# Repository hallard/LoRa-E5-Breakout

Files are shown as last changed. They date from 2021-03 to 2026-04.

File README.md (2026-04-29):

# LoRa-E5 breakout board

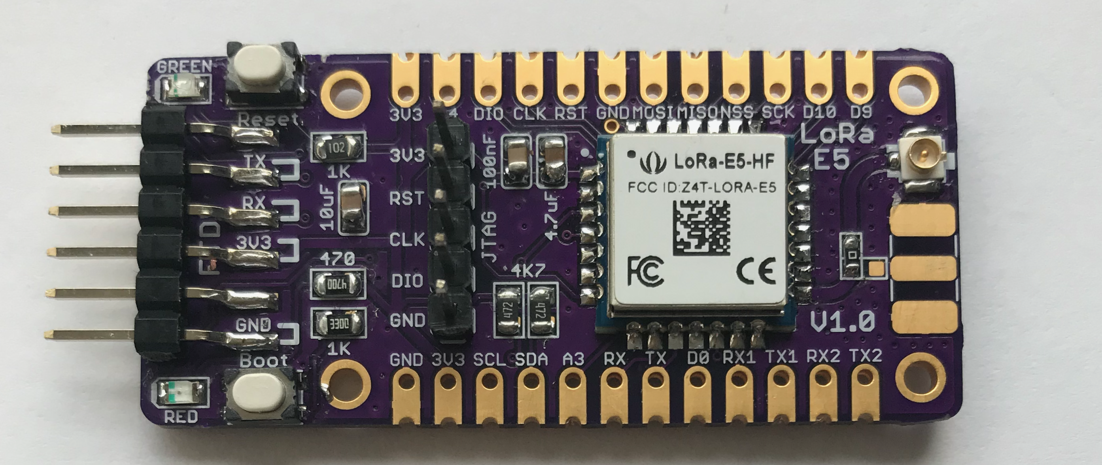
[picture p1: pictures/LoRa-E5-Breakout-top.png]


Mainly based on [LoRa-E5 mini](https://www.seeedstudio.com/LoRa-E5-mini-STM32WLE5JC-p-4869.html) board from Seedstudio, but since it was out of stock and I needed some specific wiring, I designed my own based on the Open Source design they made (thank for sharing)

I'm using mainly to flash custom firmware in it, and not using AT default firmware.

**These boards have been received, assembled, and works as expected**

- LoRa-E5 Module
- No USB/Serial, SMD FTDI 6 pins connector (**use 3.3V FTDI One, not 5V**)
- Exposed JTAG pins needed to flash module (PA13-SWDIO / PA14-SWCLK / RESET)
- Green Led on PB10
- Red Led on PB5
- Optional 2 Tactile Switch (boot and reset)
- 2 Antenna connector (u-Fl and SMA), select with 0 Ohm resistor
- I2C 4 pins location for "classic" sensors

## Detailed Description

No specific documentation for now, it's just a kind of wiring helper as schematic.

I also assume that you are familiar with all LoRaWAN stuff, all setup/infrastructure/network server/provisionning and other are out of scope of this repository.

## Schematics

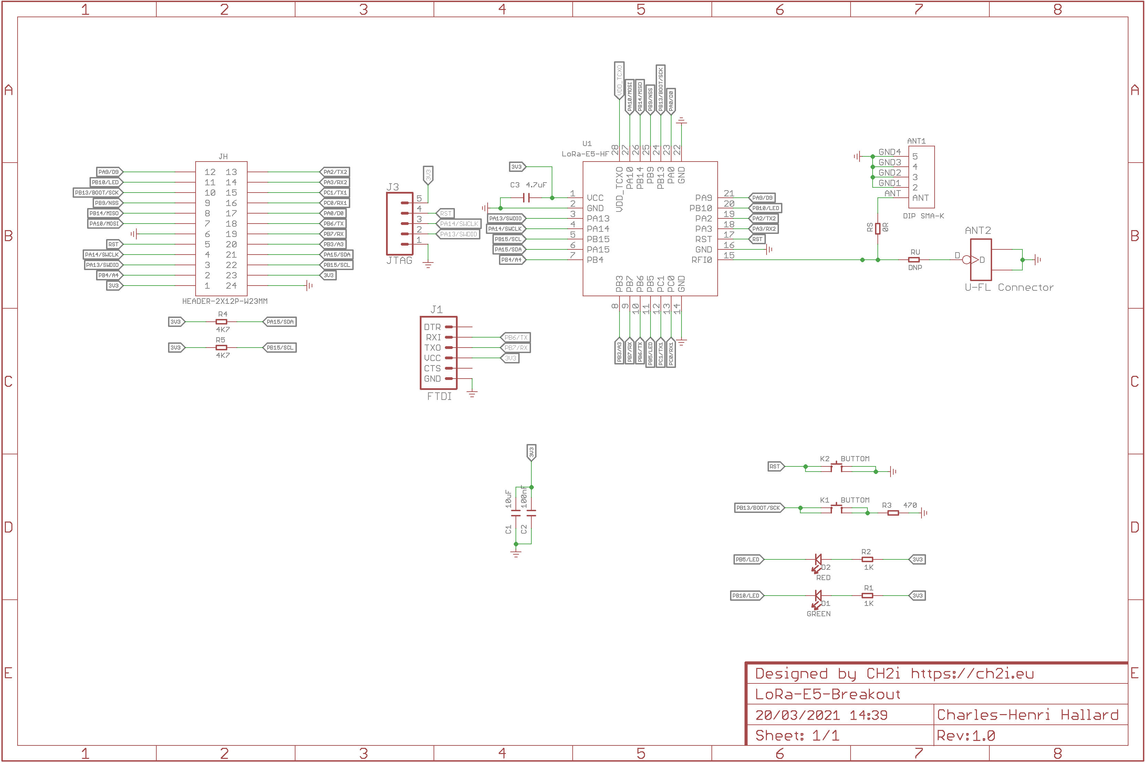
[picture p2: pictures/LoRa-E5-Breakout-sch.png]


## Boards 

~~You can order PCBs of this board at [PCBs.io][3]~~

- ~~[V1.0](https://PCBs.io/share/zM5GG)~~

 ~~PCBs.io give me some reward when you order my designed boards from their site. This is pretty good, because I can use these rewards to create and design new boards and order boards for a discounted price, so if you don't care about PCB manufacturer please use PCBs.io.~~

Looks like PCBs.io is gone, I do not have any rewards from PCBs.io since August 2020 and my free order placed after are still not received, so my guess they are not on business anymore.

So you can order the board on [oshpark](https://oshpark.com). 

- [V1.0](https://oshpark.com/shared_projects/pMgmywYX) 

It's a pitty after several discuss with OSHPark that I can't have any rewards for each people ordering my boards, this would allow me to order free PCB for shared projects and create new ones. For information my shared boards generated a total of **$285 162.00** orders at PCBs.io in 4 years, not bad at all :-)

Hoping one day OSHparks will thanks me giving them this market. 

### Assembled boards

**Top & bottom side V1.0**


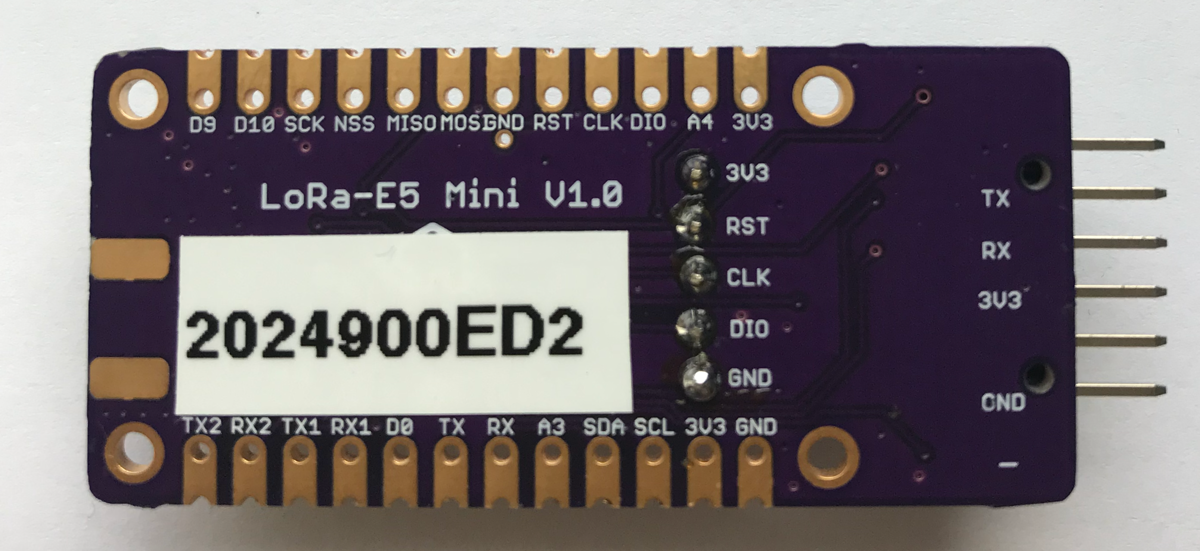
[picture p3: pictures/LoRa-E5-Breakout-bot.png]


### Bill Of Material

Nothing fancy, all components are 0805 and/or PTH and can be ordered almost anywhere (digikey, mouser, radiospare, ...). 
use only what you need dependings on what you want to do. 

Check Seeed format [BOM](https://github.com/hallard/LoRa-E5-Breakout/blob/main/LoRa-E5-Breakout-BOM.xlsx) File, check on [Seeed OPL](https://www.seeedstudio.com/opl.html) for manufacturer SKU match.

## Firmware

Before flashing any custom firmware, I strongly advise to test the board with default AT-Firmware to get the keys (even if you can use your own of course). 

Do do this, use 3.3V (and NOT 5V) FTDI USB/Serial adapter, I love this one from [sparkun](https://www.sparkfun.com/products/14050)


- Connect FTDI on the 6 pins dedicated header of the breakout
- use them a terminal application and open the port on your computer corresponding to the FTDI device
- set terminal settings to 9600 bauds 8 bits no parity 1 stop bit (8N1)
- check with at command `AT` device should anwser ``+AT: OK``

then get keys of the device

```
AT 
+AT: OK
AT+ID 
+ID: DevAddr, 24:90:05:44
+ID: DevEui, 2C:F7:F1:20:24:90:05:44
+ID: AppEui, 80:00:00:00:00:00:00:06
```

### Provision device on Network Server

For testing I'm always using The Things Network (TTN).
So next step is to provision this new device to TTN with the above keys (no need DevAddr) and get APPKEY from TTN (random generate) then get the key issued from TTN (we'll use it later below)

### Compile and flash Firmware

You can flash the board with excellent [mbed-os](https://os.mbed.com/mbed-os/) framework. 
Easy way is to use [mbed studio IDE](https://os.mbed.com/studio/). 
We added this board into [stm32customtargets](https://github.com/ARMmbed/stm32customtargets), don't hesitate to read the [readme](https://github.com/ARMmbed/stm32customtargets/blob/master/README.md). 
Finally the main firmware [mbed-os-example-lorawan](https://github.com/ARMmbed/mbed-os-example-lorawan) program.

Once IDE installed: 

- use `file` / `import program` and them import the example with URL `https://github.com/ARMmbed/mbed-os-example-lorawan`
- right click in the project name and select `Add Library` and enter `https://github.com/ARMmbed/stm32customtargets`
- open the file `custom_targets.json` from folder `stm32customtargets` and copy whole contents
- paste copied contents in the main root folder file `custom_targets.json` (yes replace the whole file) 
- open the file `mbed_app.json` and change parameters on the section `target_overrides`
    - LoRaWAN parameters such as frequency plan, OTAA, Duty Cycle, ...
    - replace keys with the ones you got from above step `lora.device-eui`, `lora.application-eui` and `lora.application-key`
- add the following section near the end of the file `mbed_app.json`.

```json
        "LORA_E5_BREAKOUT": {
            "stm32wl-lora-driver.rf_switch_config": "RBI_CONF_RFO_HP",
            "stm32wl-lora-driver.debug_tx": "PB_5",
            "stm32wl-lora-driver.debug_rx": "PB_10",
            "stm32wl-lora-driver.debug_invert": 1,
            "stm32wl-lora-driver.rf_switch_config": 2,
        }
```

When using any LoRa-E5 board you need to set the line `rf_switch_config` as above to `RBI_CONF_RFO_HP`, because hardware has not wired the mode `RBI_CONF_RFO_LP` and the stack for EU868 will try to use the `RBI_CONF_RFO_LP` (Low Power because 14dB max) path, and thus will result in unreliable signal (see #3). See this [post](https://forum.seeedstudio.com/t/lora-e5-fw-bug-tx-eu868-85ma-too-high-consumption/260126) and this [one](https://forum.rakwireless.com/t/rak3172-too-much-consumption-in-transmit-eu868/4781) for details.

Then on IDE select target "LORA_E5_BREAKOUT", build and flash with your favorite programmer (I'm using STLink) with GND/SWDIO/SWDCLK/RESET connected. 

Pay attention, that 1st time you need to erase SeeeStudio original firmware, make sure the Read Out Protection of the device is AA. If it is shown as BB, select AA and click Apply. See the end of this [section](https://wiki.seeedstudio.com/LoRa_E5_Dev_Board/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) on how to do that with STM32CubeProgrammer.

### Build and Flash

From IDE you can build the example. If you plug your STLink while project opened, mbed ide will ask you if you want to set it up for this project/target, once approved you can compile, flash and even debug from mbed ide (need some tools installed, [read](https://os.mbed.com/docs/mbed-studio/current/monitor-debug/debugging-with-mbed-studio.html), very nice.

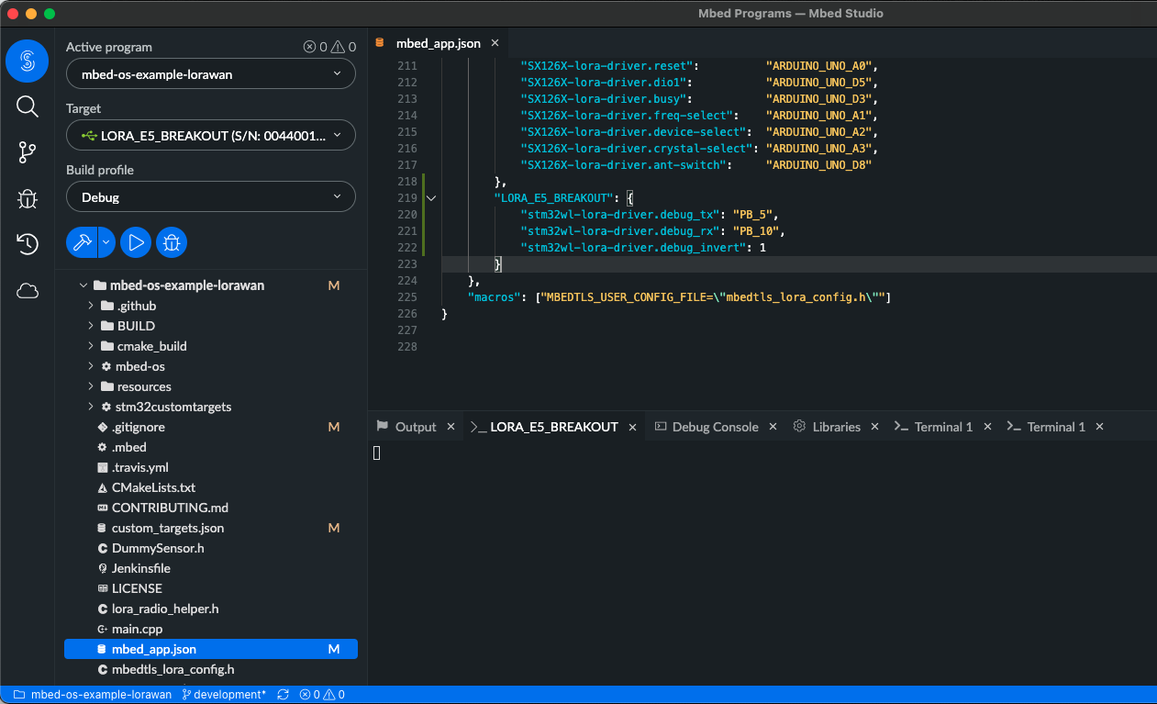
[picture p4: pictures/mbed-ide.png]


You can also see logs with the FTDI adapter and any Serial terminal set to 115200 bauds 8 bits no parity 1 stop bit (8N1)

```
Mbed LoRaWANStack initialized 
 CONFIRMED message retries : 3 
 Adaptive data  rate (ADR) - Enabled 
 Connection - In Progress ...
 Connection - Successful 
 Dummy Sensor Value = 3 
 23 bytes scheduled for transmission 
 Message Sent to Network Server 
 Dummy Sensor Value = 5 
 23 bytes scheduled for transmission 
 Message Sent to Network Server 
 Dummy Sensor Value = 7 
 23 bytes scheduled for transmission 
```

Green LED will be on when on receive mode and Red when sending data.

## License



This work is licensed under a [Creative Commons Attribution-NonCommercial-ShareAlike 4.0 International License](https://creativecommons.org/licenses/by-nc-sa/4.0/).
If you want to do commercial stuff with this project, please contact [CH2i company](https://ch2i.eu/en#support) so we can organize an simple agreement.

Original Seeed Studio reference design at https://wiki.seeedstudio.com/LoRa_E5_mini/

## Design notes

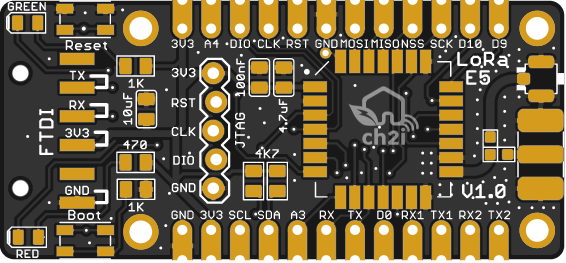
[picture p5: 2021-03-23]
pictures/LoRa-E5-Breakout.png

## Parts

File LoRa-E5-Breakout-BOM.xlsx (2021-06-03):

Designator | Seeed SKU | Qty | Description
U1 | 317990687 | 1 | LoRa-E5 STM32WLE5JC Module
C1 | 302010178 | 1 | SMD CAP Ceramic 10uF-25V-10%-X5R;0805
C2 | 302010165 | 1 | SMD CAP Ceramic 100nF-50V-10%-X7R;0805
C3 | 302010146 | 1 | SMD CAP Ceramic 4.7uF-25V-10%-X5R;0805
RS | 301012029 | 1 | SMD RES 0R-1%-1/10W;0603
R4,R5 | 301010306 | 2 | SMD RES 4.7K 0805
R1, R2 | 301010311 | 2 | SMD RES 1K 0805
R3 | 301010367 | 1 | SMD RES 470 0805
D1 | 304090043 | 1 | SMD LED Clear-Green
D2 | 304090042 | 1 | LED-SMD Red Diffused
K1,K2 | 311020518 | 2 | SMD Top Button 1.57N;4P-L4.6*W3.2*H2.5mm
ANT | 320111077 | 1 | SMD U-FL Female CONN-Gold;3P-L2.6*W2.6*H1.25mm

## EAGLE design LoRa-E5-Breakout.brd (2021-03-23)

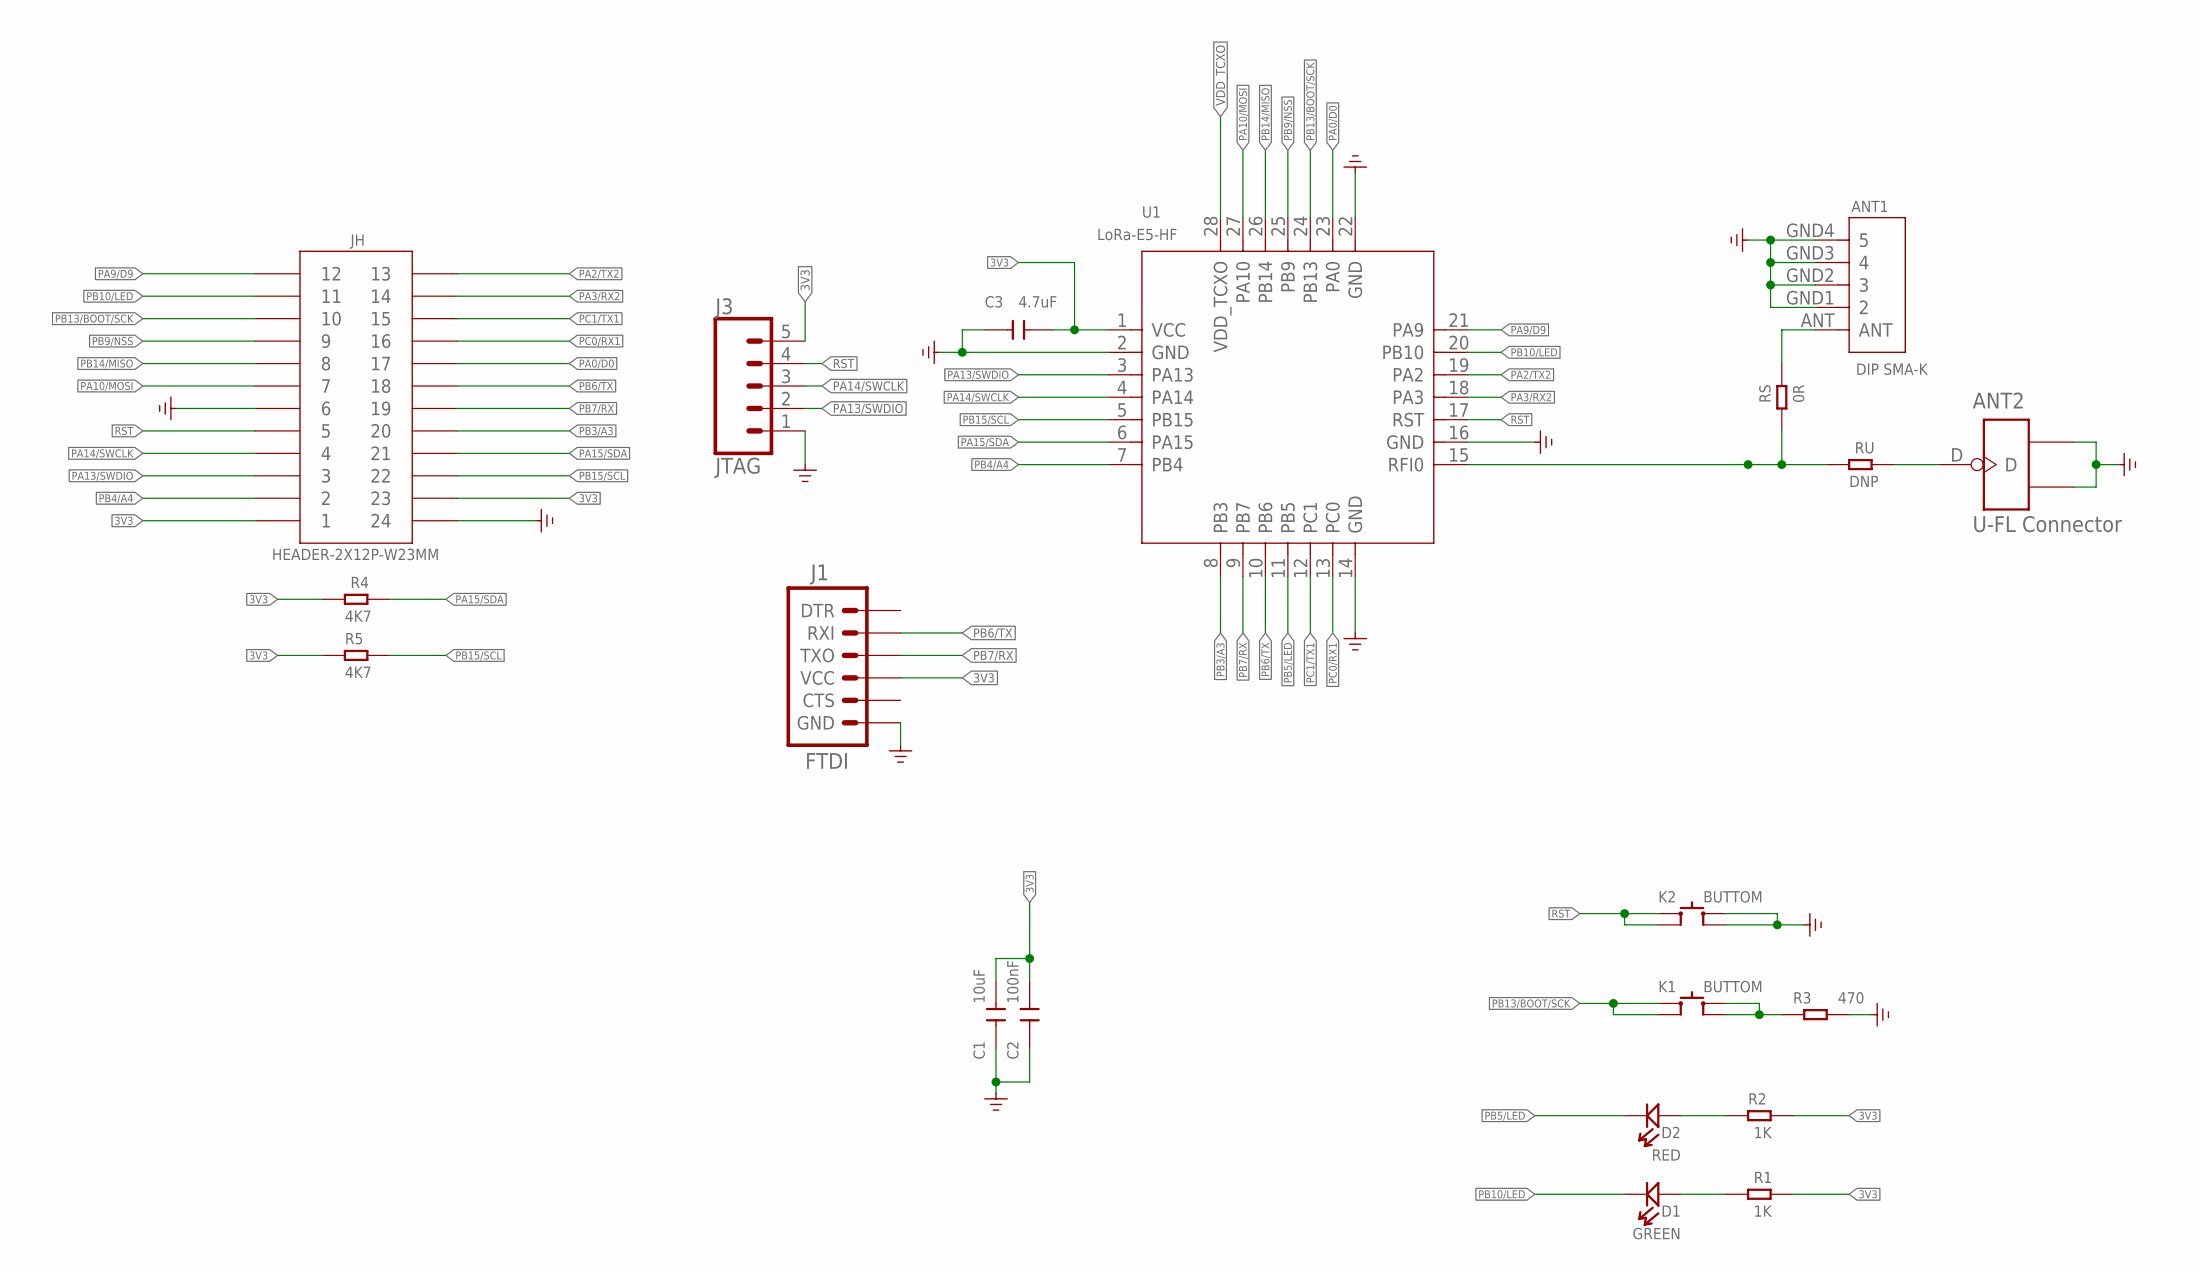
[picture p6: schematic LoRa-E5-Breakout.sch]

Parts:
ANT1: DIP SMA-K; SMA5P-SMD-5.1-6.5X6.5X16.5MM
ANT2: U-FL Connector; U-FL3P-SMD-2.6X2.6X1.0MM
C1: 10uF; C0805
C2: 100nF; C0805
C3: 4.7uF; C0805
D1: GREEN; LED-0805
D2: RED; LED-0805
J1: FTDI; 1X06-SMD_RA_MALE
J3: JTAG; 1X05_LOCK
JH: HEADER-2X12P-W23MM; H2X12-2.54-23MM
K1, K2: BUTTOM; SW4P-SMD-4.5X3.2X2.5MM
R1, R2: 1K; R0805
R3: 470; R0805
R4, R5: 4K7; R0805
RS: 0R; R0603
RU: DNP; R0603
U1: LoRa-E5-HF; MOUDLE28P-1.25-12X12X2.5MM

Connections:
3V3: C1.2, C2.2, C3.2, J1.4 (VCC), J3.5, JH.A1 (1), JH.B1 (1), JH.C11 (23), JH.D11 (23), JH.E1 (1), JH.E23 (23), JH.F1 (1), JH.F23 (23), R1.2, R2.2, R4.1, R5.1, U1.1 (VCC)
GND: ANT1.GND1 (2), ANT1.GND2 (3), ANT1.GND3 (4), ANT1.GND4 (5), ANT2.GND1, ANT2.GND2, C1.1, C2.1, C3.1, J1.6 (GND), J3.1, JH.A6 (6), JH.B6 (6), JH.C12 (24), JH.D12 (24), JH.E6 (6), JH.E24 (24), JH.F6 (6), JH.F24 (24), K2.3 (B0), K2.4 (B1), R3.2, U1.2 (GND), U1.14 (GND), U1.16 (GND), U1.22 (GND)
unnamed: D1.+, R1.1
unnamed: ANT2.D, RU.2
unnamed: D2.+, R2.1
unnamed: ANT1.ANT, RS.2
unnamed: K1.3 (B0), K1.4 (B1), R3.1
PA0/D0: JH.C5 (17), JH.D5 (17), JH.E17 (17), JH.F17 (17), U1.23 (PA0)
PA2/TX2: JH.C1 (13), JH.D1 (13), JH.E13 (13), JH.F13 (13), U1.19 (PA2)
PA3/RX2: JH.C2 (14), JH.D2 (14), JH.E14 (14), JH.F14 (14), U1.18 (PA3)
PA9/D9: JH.A12 (12), JH.B12 (12), JH.E12 (12), JH.F12 (12), U1.21 (PA9)
PA10/MOSI: JH.A7 (7), JH.B7 (7), JH.E7 (7), JH.F7 (7), U1.27 (PA10)
PA13/SWDIO: J3.2, JH.A3 (3), JH.B3 (3), JH.E3 (3), JH.F3 (3), U1.3 (PA13)
PA14/SWCLK: J3.3, JH.A4 (4), JH.B4 (4), JH.E4 (4), JH.F4 (4), U1.4 (PA14)
PA15/SDA: JH.C9 (21), JH.D9 (21), JH.E21 (21), JH.F21 (21), R4.2, U1.6 (PA15)
PB3/A3: JH.C8 (20), JH.D8 (20), JH.E20 (20), JH.F20 (20), U1.8 (PB3)
PB4/A4: JH.A2 (2), JH.B2 (2), JH.E2 (2), JH.F2 (2), U1.7 (PB4)
PB5/LED: D2.-, U1.11 (PB5)
PB6/TX: J1.2 (RXI), JH.C6 (18), JH.D6 (18), JH.E18 (18), JH.F18 (18), U1.10 (PB6)
PB7/RX: J1.3 (TXO), JH.C7 (19), JH.D7 (19), JH.E19 (19), JH.F19 (19), U1.9 (PB7)
PB9/NSS: JH.A9 (9), JH.B9 (9), JH.E9 (9), JH.F9 (9), U1.25 (PB9)
PB10/LED: D1.-, JH.A11 (11), JH.B11 (11), JH.E11 (11), JH.F11 (11), U1.20 (PB10)
PB13/BOOT/SCK: JH.A10 (10), JH.B10 (10), JH.E10 (10), JH.F10 (10), K1.1 (A0), K1.2 (A1), U1.24 (PB13)
PB14/MISO: JH.A8 (8), JH.B8 (8), JH.E8 (8), JH.F8 (8), U1.26 (PB14)
PB15/SCL: JH.C10 (22), JH.D10 (22), JH.E22 (22), JH.F22 (22), R5.2, U1.5 (PB15)
PC0/RX1: JH.C4 (16), JH.D4 (16), JH.E16 (16), JH.F16 (16), U1.13 (PC0)
PC1/TX1: JH.C3 (15), JH.D3 (15), JH.E15 (15), JH.F15 (15), U1.12 (PC1)
RF: RS.1, RU.1, U1.15 (RFI0)
RST: J3.4, JH.A5 (5), JH.B5 (5), JH.E5 (5), JH.F5 (5), K2.1 (A0), K2.2 (A1), U1.17 (RST)
VDD_TCXO: U1.28 (VDD_TCXO)

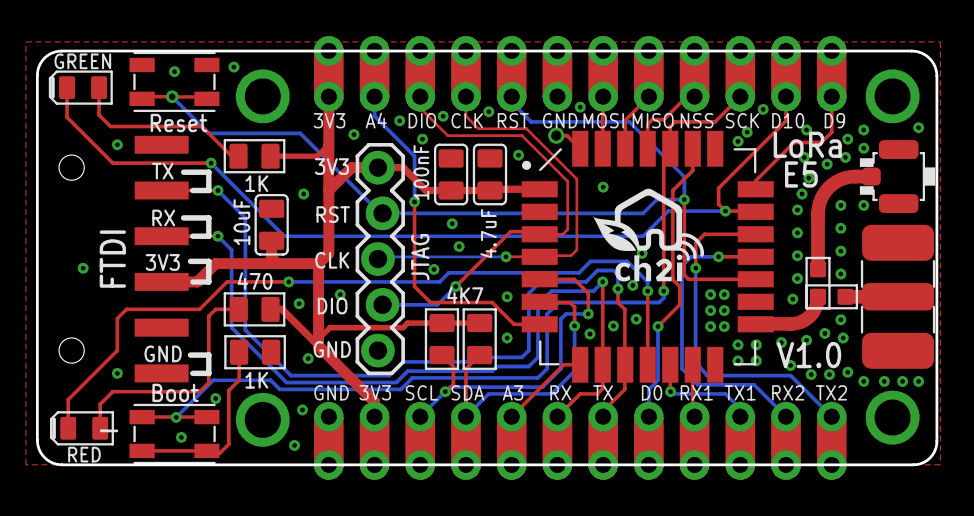
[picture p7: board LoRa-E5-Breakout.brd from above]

Board: 2 copper layers, 50.0 x 23.0 mm, 22 parts (1 on the bottom side), 29 nets.

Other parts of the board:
U$1, U$2: LOGO_C2I_015

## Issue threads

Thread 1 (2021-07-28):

UART Bootloader?

evandavey, 2021-07-28:
Hi @hallard ,

My (original) LoRa E5 mini boards have arrived.  Have you looked into programming via UART (via USB) rather than requiring an ST-LINK?

hallard, 2021-07-28:
Great you have it to play with.
No I didn’t tried but for that you need to setup the board into Seeed custom board bootloader starting/resetting the board pulling boot pin to low. Pay attention it’s not the original STM32 boot pin, it’s just a gpio tested in seeed firmware to put it into update mode.
But this is working only for seeed firmware once you erased original FW to flash again you need a external programmer except if you implement serial FW update in your code of course.

evandavey, 2021-07-28:
OK thanks.  Posted in the SeeedStudio forums to see if anyone has written a bootloader.
I guess the STM32 boot pin is not available then?  Otherwise, couldn't we just put it into DFU mode and then use STM32CubeProgrammer.

hallard, 2021-07-28:
Yes it’s not exposed but not sure to understand the issue, I have no problem flashing the device using stlink v3 mod (7€) with swio, swclk, rst pins

hallard, 2021-07-28:
If you want to flash with serial something interesting here https://www.st.com/resource/en/application_note/cd00264342-usart-protocol-used-in-the-stm32-bootloader-stmicroelectronics.pdf

evandavey, 2021-07-28:
Yep - will be able to flash it that way but that means a debugger always connected and less convienient (particularly for low power measurements as the debugger probably needs to be disconnected each time).  Also makes it less accessible as a product.  For example, getting a non-technical user to upload firmware (much easier for them to just plug into USB then run an update script).

A software jump seems the most promising option to get back into STM32 DFU.  So hoping, I could use the ST-LINK for the initial load and then software jump on the fake boot pin.

evandavey, 2021-07-28:
Regarding the link, the trick is getting it into DFU mode first (then STM32CubeProgrammer can use UART).  But maybe this is implying you can send 0x7F on boot to kick it into DFU, will dig a bit deeper.

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

hallard, 2021-07-28:
Oh I see, FYI when we discussed on Mbed issue about low power my measurement were taken within jtag connected pins io, clk, rst and never changed consumption to my surprise and it flash to quick that I never changed mode, but I have a secret I give end user a custom board that makes flash so easy

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

hallard, 2021-07-28:
In all case it’s a shame real boot pin not exposed on RAK it is. May be as you stated is to setup this mode by software if it’s possible of course

evandavey, 2021-07-28:
Ah, nice.  I will try with the ST-LINK tomorrow.  I'll admit I jumped straight to UART as I hoped it would be that straight-forward (and programming via USB is really the way any modern board should work).  If I get adventurous I might peek under the can of the module but maybe they prioritised other functionality with limited pins available.

Closed 2022-03-17.

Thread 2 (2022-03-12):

Bad RF performance with mbed os

Mircerson, 2022-03-12:
Hi there,

Just want to say great work on the module and board, looks solid.

Using the latest mbed os LoRaWan example and the latest custom targets library, the RF performance is quite bad ( i.e. RSSI over -100 and SNR of around 0 to -5 when placed close to the gateway). I am using an off-the-shelf antenna ( Linx USP-410 ) and the RL is around -13 dB which is quite decent ( without any matching ).

I have tested the same board with the STM32Cube example from Seeed's website and it's significantly better ( i.e. RSSI -38-40 and SNR of 10 or more ) in the same spot.

Not sure you have experienced something like that using the Seeed E5 modules in the past?

Thanks,
Mircea

Mircerson, 2022-03-13:
Adding the following to the custom target seems to fix this:
"stm32wl-lora-driver.rf_switch_config":"RBI_CONF_RFO_HP"

Closed 2022-03-13.

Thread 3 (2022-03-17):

low tx power

m0rphex, 2022-03-17:
Hi and thank you for your work with the LoRa E5. I'm using mbed os and mbed studio with the LORA_E5_MINI target which is the board I have at hand. I can build and flash the lorawan example code, but the device is transmitting at a very low power. Also when I join TTN with my own forwarder gateway the packet transmission interval is ~6 seconds with duty cycle enabled (too fast). I'm wondering whether there is a problem with the antenna RF switching and other declarations. Which version of mbed os have you used with the e5 breakout board. Any insight into this would be much appreciated.

hallard, 2022-03-17:
@m0rphex you need to use version 6.15 (with power fix, but that does not seems to be optimal because of hardware design) but if you need more power, use version 6.14 (before my patch) to see this [PR](https://github.com/ARMmbed/mbed-os/pull/15017)

Also use latest` stm32customtargets` as indicated in the readme. Best would be you post your `mbed_app.json` file to see

m0rphex, 2022-03-17:
@hallard thank you for the prompt answer. I've tried mbed 6.14 without any difference in tx power, its still too low when I monitor my sdr dongle. I'm able to get proper output with the seeed studio LoRaWAN node example and AT firmware. I don't have exact measurements but the tx seems to be well below 14dBm. Could you point out where I could have a look at configuring the PA settings. It's been a few years since I last used mbed os, much has changed :) What kind of RSSI values have you been getting with the mbed LoRaWAN example and the E5 Breakout? My mbed_app.json is not modified, ive tried the LORA_E5_BREAKOUT overrides, but I don't think that's the problem here.

hallard, 2022-03-17:
Do you have setup `RBI_CONF_RFO_HP` in `mbed_conf.json` as an example below?

```
json
"target_overrides": {
        "*": {
            "stm32wl-lora-driver.rf_switch_config": "RBI_CONF_RFO_HP",
            "stm32wl-lora-driver.debug_rx": "LED1",
            "stm32wl-lora-driver.debug_tx": "LED2",
            "stm32wl-lora-driver.debug_invert": 1,
            "lora.over-the-air-activation": true,
            "lora.duty-cycle-on": true,
            "lora.phy": "EU868",
        },
```

As far as I remember, node near GW got RSSI between -40/-30

Mircerson, 2022-03-18:
Hi,
Had the same issue.
You need "stm32wl-lora-driver.rf_switch_config": "RBI_CONF_RFO_HP" in the mbed_conf.json file ;)

m0rphex, 2022-03-19:
Thank you `"stm32wl-lora-driver.rf_switch_config": "RBI_CONF_RFO_HP"` solved the issue!

hallard, 2022-03-19:
thanks for the headup, I've updated the read me file according to.

Closed 2022-03-19.

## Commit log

2021-06-03 Assembled boards
2021-06-03 Added BOM File
    [LoRa-E5-Breakout-BOM.xlsx]
2021-06-03 BOM link
2021-08-18 Fix bad power signal

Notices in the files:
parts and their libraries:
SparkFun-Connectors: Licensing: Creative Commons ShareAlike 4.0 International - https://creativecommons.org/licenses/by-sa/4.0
